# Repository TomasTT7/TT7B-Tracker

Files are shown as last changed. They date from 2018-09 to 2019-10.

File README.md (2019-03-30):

# TT7B-Tracker
This is the main repository for TT7B superpressure balloon tracker. It includes the board and schematic design files for Eagle, the current firmware and a couple of python scripts for decoding telemetry.

The tracker is in detail described in these two blog posts: [The TT7B Tracker](https://tt7hab.blogspot.com/2018/09/the-tt7b-tracker.html) and [The TT7B Tracker Vol. 2](https://tt7hab.blogspot.com/2019/03/the-tt7b-tracker-vol-2.html).

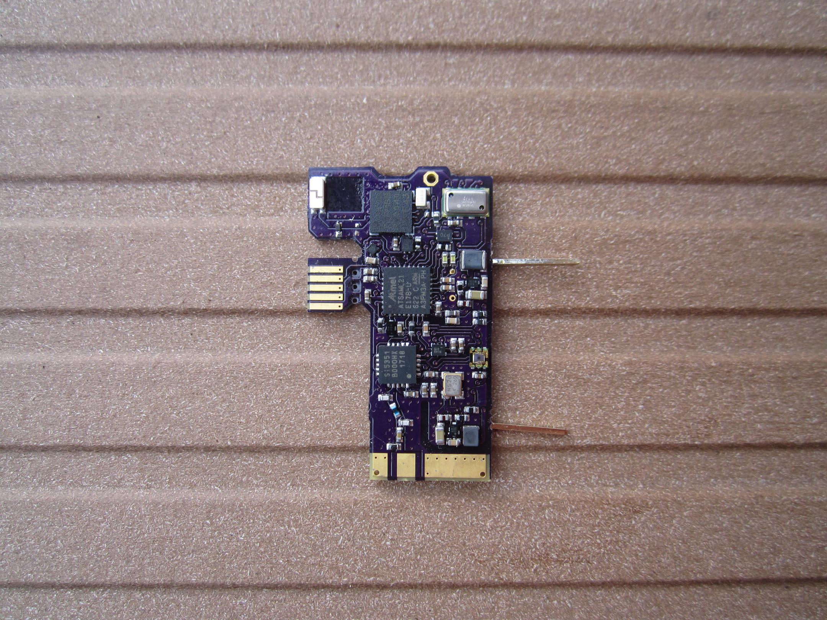
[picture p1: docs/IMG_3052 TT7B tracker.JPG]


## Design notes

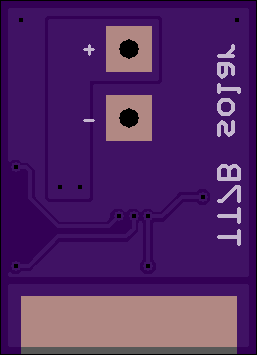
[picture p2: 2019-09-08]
Hardware/SPV1040 v1.0 bottom.png

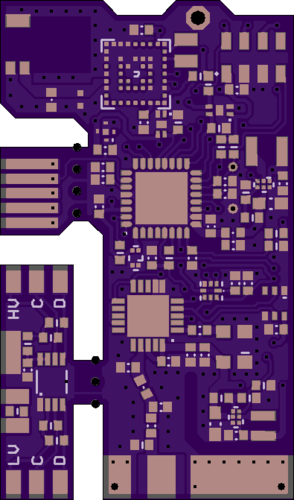
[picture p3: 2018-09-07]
Hardware/TT7B v1.0 top.png

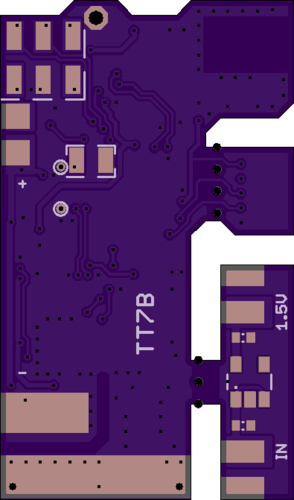
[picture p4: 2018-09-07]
Hardware/TT7B v1.0 bottom.png

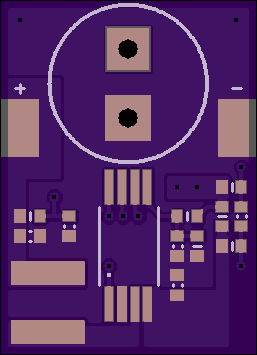
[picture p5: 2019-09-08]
Hardware/SPV1040 v1.0 top.png

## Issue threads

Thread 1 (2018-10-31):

LoRa_Gateway.py

SwiftFlying, 2018-10-31:
Hi,
I can't run the PY file. Can I send a EXE file to me?
Traceback (most recent call last):
File "C:\Users\hp1\Desktop\OV5640\LoRa_Gateway.py", line 30, in
from Tkinter import *
ModuleNotFoundError: No module named 'Tkinter'

TomasTT7, 2018-10-31:
You have to install all the modules LoRa_Gateway.py imports at the top of
the code to your Python. That is what the error is telling you. I don't
have an EXE file, I run it from python.

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

SwiftFlying, 2018-11-01:
LoRa_Gateway.py is finally able to run. Thank you for your help!

SwiftFlying, 2018-11-03:
Hi,
Is there any way to completely solve the problem of image errors?
I read your article. You found that the error was not from LORA transmission.It's from camera part。
Is there any interest in solving this problem completely?I can help you redesign the PCB part.I can make a new prototype for you.Of course, we can also switch to other camera tests.

SwiftFlying, 2018-11-19:
Hi,
I encountered a problem, unable to display the received pictures.
2018-11-18 20:31:50.76 SSDV from: TT7L ImageID: 2 PacketID: 0 1024x768 Quality: 4 No-FEC   snr: 42 rssi: -21 err: -0.4
2018-11-18 20:31:51.03 SSDV from: TT7L ImageID: 2 PacketID: 1 1024x768 Quality: 4 No-FEC   snr: 42 rssi: -21 err: -0.4
2018-11-18 20:31:51.33 SSDV from: TT7L ImageID: 2 PacketID: 2 1024x768 Quality: 4 No-FEC   snr: 41 rssi: -22 err: -0.4
2018-11-18 20:31:51.58 SSDV from: TT7L ImageID: 2 PacketID: 3 1024x768 Quality: 4 No-FEC   snr: 42 rssi: -22 err: -0.4
2018-11-18 20:31:51.86 SSDV from: TT7L ImageID: 2 PacketID: 4 1024x768 Quality: 4 No-FEC   snr: 42 rssi: -21 err: -0.4
2018-11-18 20:31:52.14 SSDV from: TT7L ImageID: 2 PacketID: 5 1024x768 Quality: 4 No-FEC   snr: 43 rssi: -21 err: -0.4
2018-11-18 20:31:52.39 SSDV from: TT7L ImageID: 2 PacketID: 6 1024x768 Quality: 4 No-FEC   snr: 44 rssi: -21 err: -0.4
2018-11-18 20:31:52.67 SSDV from: TT7L ImageID: 2 PacketID: 7 1024x768 Quality: 4 No-FEC   snr: 44 rssi: -21 err: -0.4
2018-11-18 20:31:52.95 SSDV from: TT7L ImageID: 2 PacketID: 8 1024x768 Quality: 4 No-FEC   snr: 42 rssi: -21 err: -0.4
2018-11-18 20:31:53.23 SSDV from: TT7L ImageID: 2 PacketID: 9 1024x768 Quality: 4 No-FEC   snr: 42 rssi: -22 err: -0.4
2018-11-18 20:31:53.51 SSDV from: TT7L ImageID: 2 PacketID: 10 1024x768 Quality: 4 No-FEC   snr: 43 rssi: -22 err: -0.4
2018-11-18 20:31:53.76 SSDV from: TT7L ImageID: 2 PacketID: 11 1024x768 Quality: 4 No-FEC   snr: 43 rssi: -21 err: -0.4
2018-11-18 20:31:54.04 SSDV from: TT7L ImageID: 2 PacketID: 12 1024x768 Quality: 4 No-FEC   snr: 42 rssi: -23 err: -0.4
2018-11-18 20:31:54.29 SSDV from: TT7L ImageID: 2 PacketID: 13 1024x768 Quality: 4 No-FEC   snr: 41 rssi: -22 err: -0.4
2018-11-18 20:31:54.58 SSDV from: TT7L ImageID: 2 PacketID: 14 1024x768 Quality: 4 No-FEC   snr: 41 rssi: -22 err: -0.4
2018-11-18 20:31:54.87 SSDV from: TT7L ImageID: 2 PacketID: 15 1024x768 Quality: 4 No-FEC   snr: 40 rssi: -25 err: -0.4
2018-11-18 20:31:55.22 SSDV from: TT7L ImageID: 2 PacketID: 16 1024x768 Quality: 4 No-FEC   snr: 42 rssi: -23 err: -0.4
2018-11-18 20:31:55.42 SSDV from: TT7L ImageID: 2 PacketID: 17 1024x768 Quality: 4 No-FEC   snr: 41 rssi: -22 err: -0.4
2018-11-18 20:31:55.68 SSDV from: TT7L ImageID: 2 PacketID: 18 1024x768 Quality: 4 No-FEC   snr: 40 rssi: -22 err: -0.4
2018-11-18 20:31:55.95 SSDV from: TT7L ImageID: 2 PacketID: 19 1024x768 Quality: 4 No-FEC   snr: 41 rssi: -23 err: -0.4
2018-11-18 20:31:56.22 SSDV from: TT7L ImageID: 2 PacketID: 20 1024x768 Quality: 4 No-FEC   snr: 41 rssi: -24 err: -0.4
2018-11-18 20:31:56.51 SSDV from: TT7L ImageID: 2 PacketID: 21 1024x768 Quality: 4 No-FEC   snr: 41 rssi: -23 err: -0.4
2018-11-18 20:31:56.78 SSDV from: TT7L ImageID: 2 PacketID: 22 1024x768 Quality: 4 No-FEC   snr: 43 rssi: -22 err: -0.4
2018-11-18 20:31:57.04 SSDV from: TT7L ImageID: 2 PacketID: 23 1024x768 Quality: 4 No-FEC   snr: 42 rssi: -21 err: -0.4
2018-11-18 20:31:57.31 SSDV from: TT7L ImageID: 2 PacketID: 24 1024x768 Quality: 4 No-FEC   snr: 41 rssi: -22 err: -0.4
2018-11-18 20:31:57.58 SSDV from: TT7L ImageID: 2 PacketID: 25 1024x768 Quality: 4 No-FEC   snr: 42 rssi: -23 err: -0.4
2018-11-18 20:31:57.87 SSDV from: TT7L ImageID: 2 PacketID: 26 1024x768 Quality: 4 No-FEC   snr: 41 rssi: -22 err: -0.4
2018-11-18 20:31:58.14 SSDV from: TT7L ImageID: 2 PacketID: 27 1024x768 Quality: 4 No-FEC   snr: 42 rssi: -23 err: -0.4
2018-11-18 20:31:58.42 SSDV from: TT7L ImageID: 2 PacketID: 28 1024x768 Quality: 4 No-FEC   snr: 43 rssi: -22 err: -0.4
2018-11-18 20:31:58.68 SSDV from: TT7L ImageID: 2 PacketID: 29 1024x768 Quality: 4 No-FEC   snr: 42 rssi: -23 err: -0.4
2018-11-18 20:31:58.97 SSDV from: TT7L ImageID: 2 PacketID: 30 1024x768 Quality: 4 No-FEC   snr: 40 rssi: -23 err: -0.4
2018-11-18 20:31:59.25 SSDV from: TT7L ImageID: 2 PacketID: 31 1024x768 Quality: 4 No-FEC   snr: 42 rssi: -23 err: -0.4
2018-11-18 20:31:59.53 SSDV from: TT7L ImageID: 2 PacketID: 32 1024x768 Quality: 4 No-FEC   snr: 41 rssi: -23 err: -0.4
2018-11-18 20:31:59.81 SSDV from: TT7L ImageID: 2 PacketID: 33 1024x768 Quality: 4 No-FEC   snr: 41 rssi: -23 err: -0.4
2018-11-18 20:32:00.06 SSDV from: TT7L ImageID: 2 PacketID: 34 1024x768 Quality: 4 No-FEC   snr: 40 rssi: -23 err: -0.4
2018-11-18 20:32:00.36 SSDV from: TT7L ImageID: 2 PacketID: 35 1024x768 Quality: 4 No-FEC   snr: 41 rssi: -23 err: -0.4
2018-11-18 20:32:00.62 SSDV from: TT7L ImageID: 2 PacketID: 36 1024x768 Quality: 4 No-FEC   snr: 42 rssi: -23 err: -0.4
2018-11-18 20:32:00.90 SSDV from: TT7L ImageID: 2 PacketID: 37 1024x768 Quality: 4 No-FEC   snr: 41 rssi: -23 err: -0.4
2018-11-18 20:32:01.17 SSDV from: TT7L ImageID: 2 PacketID: 38 1024x768 Quality: 4 No-FEC   snr: 39 rssi: -24 err: -0.4
2018-11-18 20:32:01.45 SSDV from: TT7L ImageID: 2 PacketID: 39 1024x768 Quality: 4 No-FEC   snr: 39 rssi: -24 err: -0.4
2018-11-18 20:32:01.75 SSDV from: TT7L ImageID: 2 PacketID: 40 1024x768 Quality: 4 No-FEC   snr: 41 rssi: -23 err: -0.4
2018-11-18 20:32:02.00 SSDV from: TT7L ImageID: 2 PacketID: 41 1024x768 Quality: 4 No-FEC   snr: 41 rssi: -23 err: -0.4
2018-11-18 20:32:02.28 SSDV from: TT7L ImageID: 2 PacketID: 42 1024x768 Quality: 4 No-FEC   snr: 40 rssi: -24 err: -0.4
2018-11-18 20:32:02.56 SSDV from: TT7L ImageID: 2 PacketID: 43 1024x768 Quality: 4 No-FEC   snr: 42 rssi: -24 err: -0.4
2018-11-18 20:32:02.84 SSDV from: TT7L ImageID: 2 PacketID: 44 1024x768 Quality: 4 No-FEC   snr: 41 rssi: -24 err: -0.4
2018-11-18 20:32:03.14 SSDV from: TT7L ImageID: 2 PacketID: 45 1024x768 Quality: 4 No-FEC   snr: 42 rssi: -23 err: -0.4
2018-11-18 20:32:03.39 SSDV from: TT7L ImageID: 2 PacketID: 46 1024x768 Quality: 4 No-FEC   snr: 39 rssi: -24 err: -0.4
2018-11-18 20:32:03.67 SSDV from: TT7L ImageID: 2 PacketID: 47 1024x768 Quality: 4 No-FEC   snr: 41 rssi: -24 err: -0.4
2018-11-18 20:32:03.95 SSDV from: TT7L ImageID: 2 PacketID: 48 1024x768 Quality: 4 No-FEC   snr: 43 rssi: -24 err: -0.4
2018-11-18 20:32:22.06 SSDV from: TT7L ImageID: 2 PacketID: 49 1024x768 Quality: 4 No-FEC   snr: 40 rssi: -22 err: -0.4
2018-11-18 20:32:23.17 SSDV from: TT7L ImageID: 2 PacketID: 53 1024x768 Quality: 4 No-FEC   snr: 24 rssi: -22 err: -0.4

How should I solve this problem?
Tom

TomasTT7, 2018-11-19:
Hi,

the gateway requires the following piece of code compiled in the main
folder as "SSDV.exe":

https://github.com/fsphil/ssdv

That is the code that decodes the packets to jpeg images and is called by
subprocess.Popen(args, shell=True) from decode_ssdv().

Tomas

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

SwiftFlying, 2018-11-19:
Thank you ！
I need to download the source code from here. https://github.com/fsphil/ssdv
Compile a APP "SSDV.exe" Sorry, I'm not very good at software.   What platform should I use to compile it?

Tom

TomasTT7, 2018-11-19:
I am sure there are more ways of compiling the code. I used Codeblocks.

If you don't want to bother with it, try downloading the exe file from my
google drive:

https://drive.google.com/open?id=1MGWpKZtEY6ANgXkNepjeXgWCe6bpOrCC

Tomas

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

SwiftFlying, 2018-11-22:
Thank you! Finally succeeded.

Closed 2019-11-03.

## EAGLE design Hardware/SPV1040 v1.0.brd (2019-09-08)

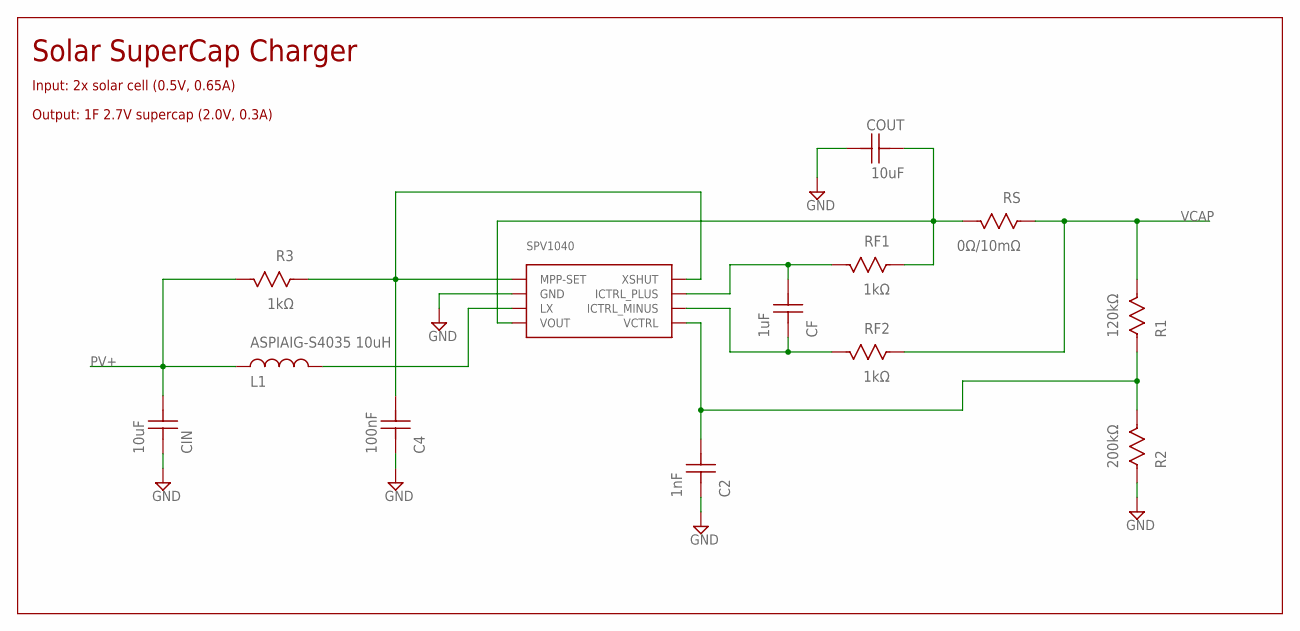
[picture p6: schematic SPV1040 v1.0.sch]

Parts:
C2: 1nF; CAP0402
C4: 100nF; CAP0402
CF: 1uF; CAP0402
CIN: 10uF; CAP0402
COUT: 10uF; CAP0402
L1: ASPIAIG-S4035 10uH; ASPIAIG-S4035
R1: 120kΩ; RES0402
R2: 200kΩ; RES0402
R3: 1kΩ; RES0402
RF1, RF2: 1kΩ; RES0402
RS: 0Ω/10mΩ; RES0402
U1: SPV1040

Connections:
GND: C2.P$1, C4.P$1, CIN.P$1, COUT.P$2, R2.P$1, U1.GND
N11: C4.P$2, R3.P$1, U1.MPP-SET, U1.XSHUT
unnamed: CF.P$2, RF1.P$2, U1.ICTRL_PLUS
unnamed: CF.P$1, RF2.P$2, U1.ICTRL_MINUS
unnamed: COUT.P$1, RF1.P$1, RS.P$2, U1.VOUT
unnamed: C2.P$2, R1.P$1, R2.P$2, U1.VCTRL
unnamed: L1.P$2, U1.LX
PV+: CIN.P$2, L1.P$1, R3.P$2
VCAP: R1.P$2, RF2.P$1, RS.P$1

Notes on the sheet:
Solar SuperCap Charger
Input: 2x solar cell (0.5V, 0.65A)
Output: 1F 2.7V supercap (2.0V, 0.3A)

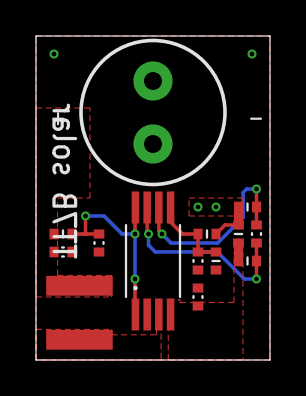
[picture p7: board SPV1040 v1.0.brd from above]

Board: 2 copper layers, 13.0 x 18.0 mm, 13 parts (0 on the bottom side), 9 nets.

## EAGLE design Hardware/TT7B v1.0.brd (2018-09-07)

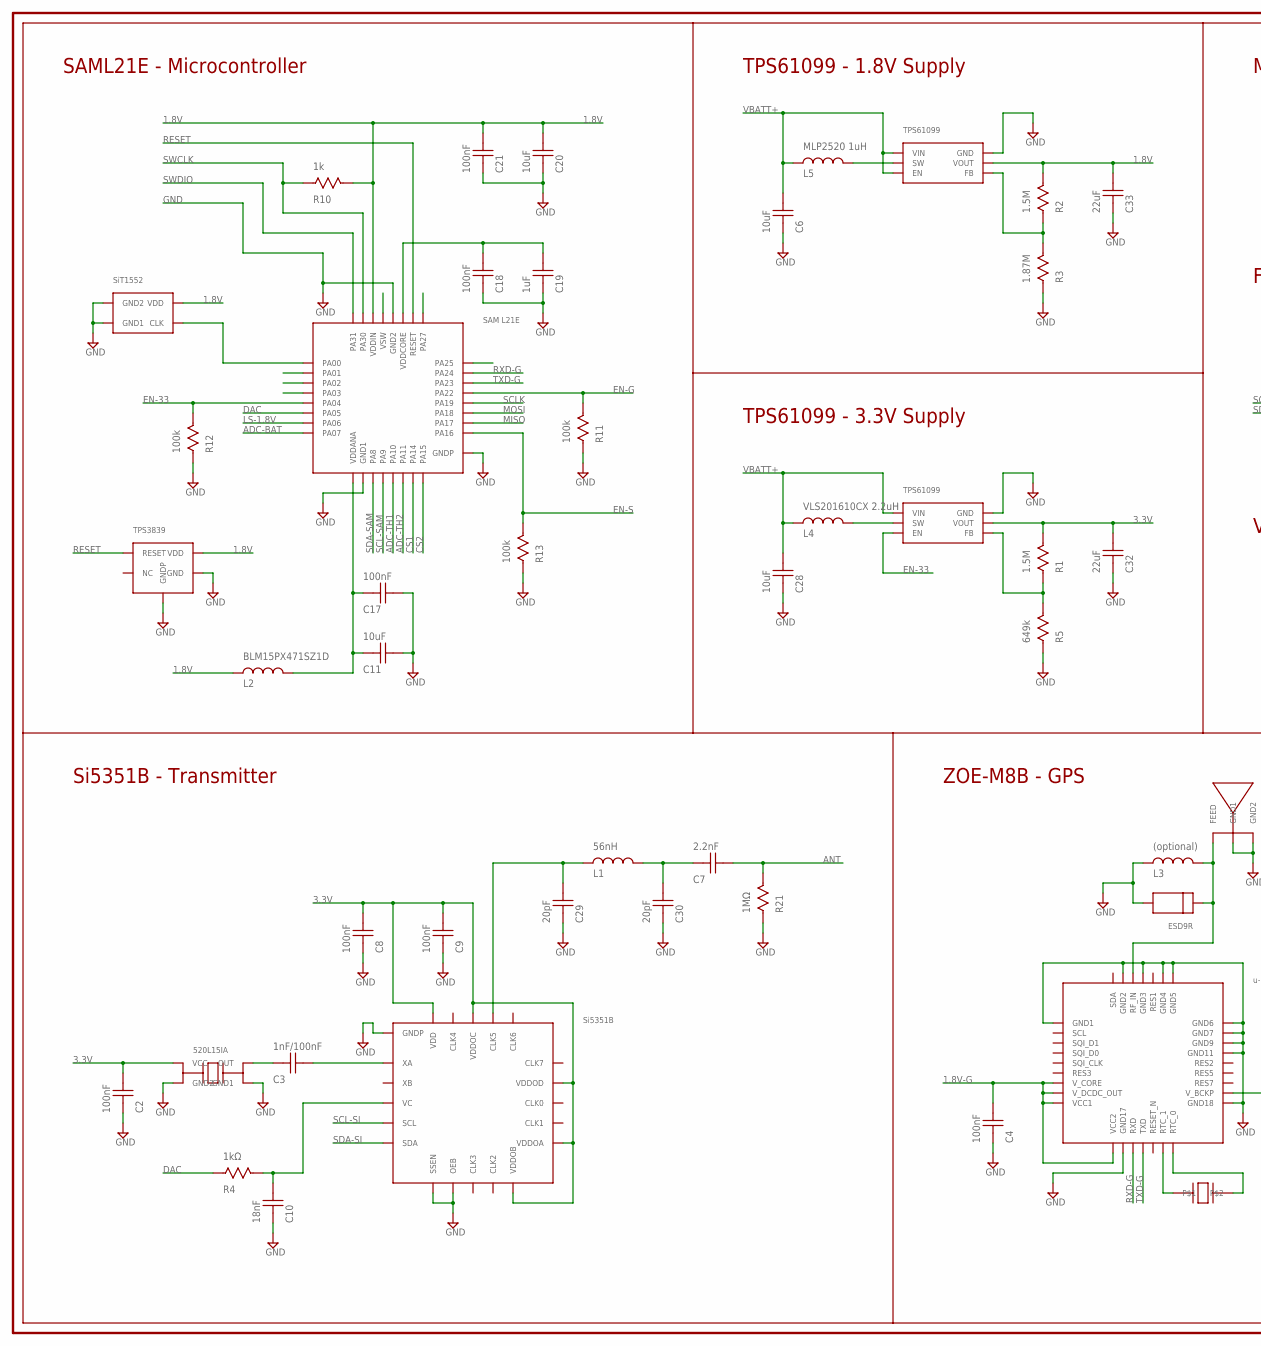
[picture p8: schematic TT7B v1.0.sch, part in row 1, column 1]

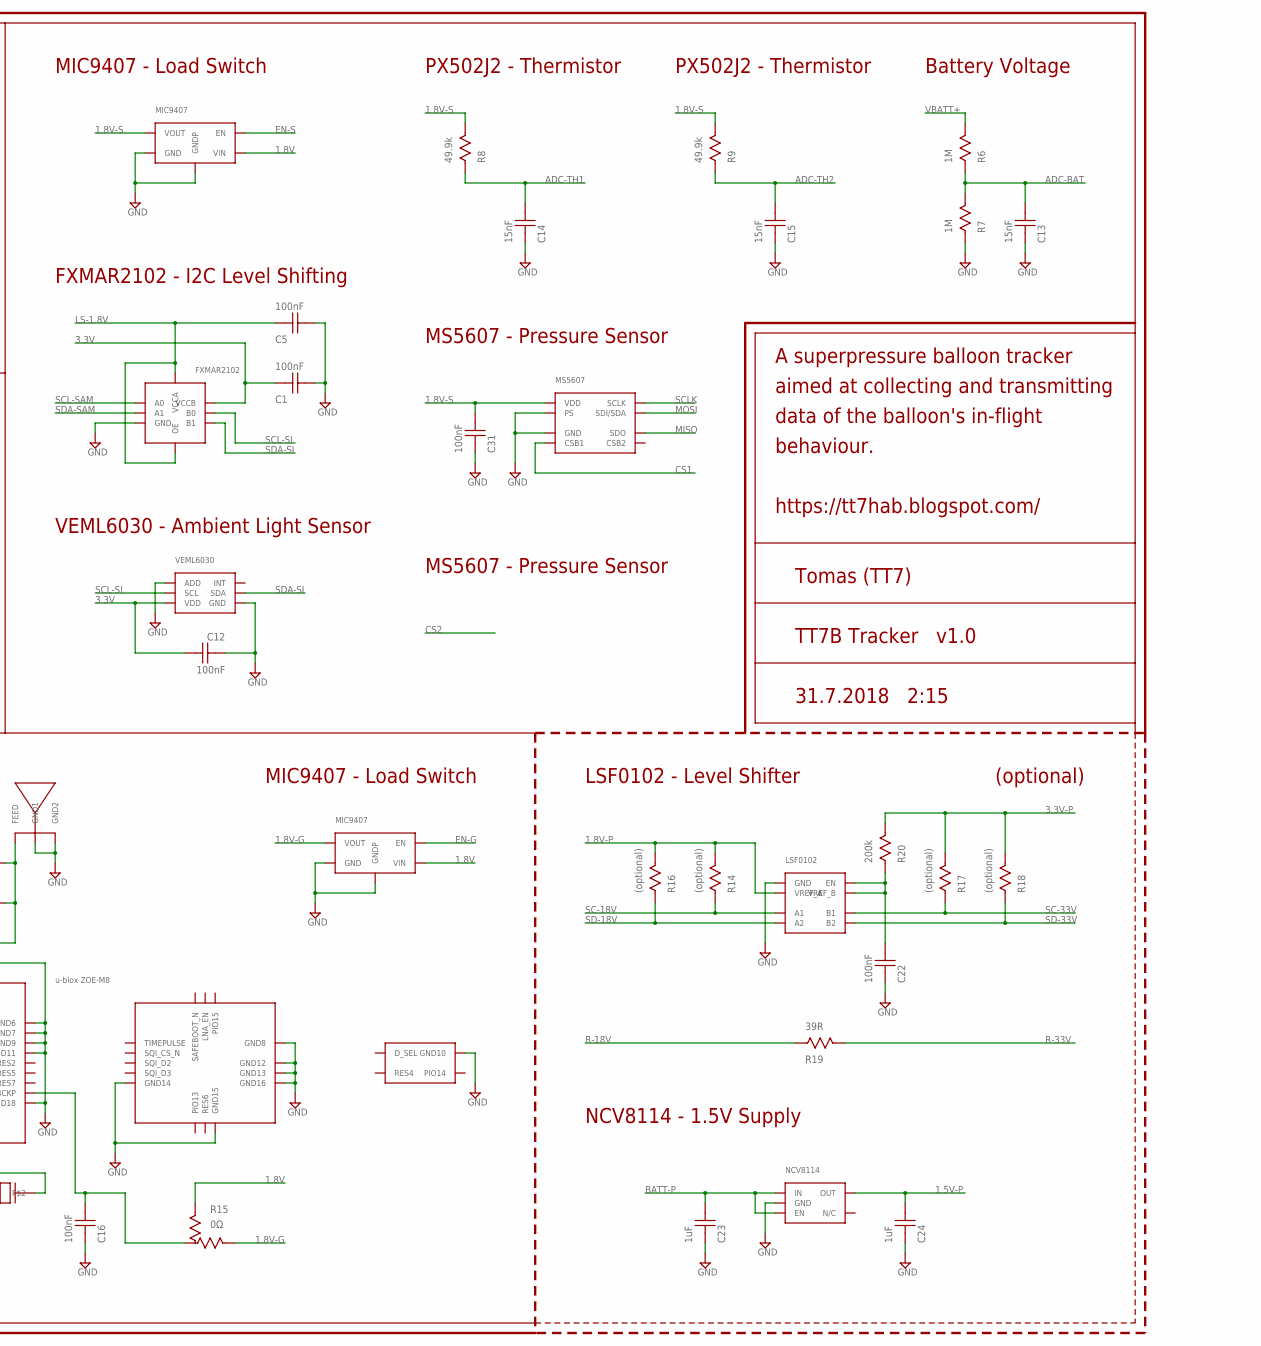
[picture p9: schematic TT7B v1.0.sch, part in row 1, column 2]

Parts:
C1, C2, C4, C5, C8, C9, C12, C16, C17, C18, C21, C22, C31: 100nF; CAP0402
C3: 1nF/100nF; CAP0402
C6, C11, C20, C28: 10uF; CAP0402
C7: 2.2nF; CAP0402
C10: 18nF; CAP0402
C13, C14, C15: 15nF; CAP0402
C19, C23, C24: 1uF; CAP0402
C29, C30: 20pF; CAP0402
C32, C33: 22uF; CAP0603
D1: ESD9R
L1: 56nH; IND0402
L2: BLM15PX471SZ1D; IND0402
L3: (optional); IND0402
L4: VLS201610CX 2.2uH; VLS201610CX
L5: MLP2520 1uH; MLP2520
R1, R2: 1.5M; RES0402
R3: 1.87M; RES0402
R4: 1kΩ; RES0402
R5: 649k; RES0402
R6, R7: 1M; RES0402
R8, R9: 49.9k; RES0402
R10: 1k; RES0402
R11, R12, R13: 100k; RES0402
R14, R16, R17, R18: (optional); RES0402
R15: 0Ω; RES0402-3
R19: 39R; RES0402
R20: 200k; RES0402
R21: 1MΩ; RES0402
U1: SAML21E18B-MUT
U2: UBLOX_ZOE-M8
U3: FXMAR2102
U4: 520L15IA
U5: CM8V-T1A
U6, U13: MIC9407
U7: MS5607
U8: LSF0102
U9: NCV8114
U10: W3011A
U11: SI5351B
U12: TPS3839; TPS383
U14: SIT1552
U15: VEML6030
U16, U17: TPS61099

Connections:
1.5V-P: C24.P$2, U9.OUT
1.8V: C20.P$2, C21.P$2, C33.P$2, L2.P$1, R2.P$2, R10.P$2, R15.1, U1.VDDIN, U6.VIN, U12.VDD, U13.VIN, U14.VDD, U16.VOUT
1.8V-G: C4.P$2, R15.3, U2.VCC1, U2.VCC2, U2.V_CORE, U2.V_DCDC_OUT, U6.VOUT
1.8V-P: R14.P$2, R16.P$2, U8.VREF_A
1.8V-S: C31.P$2, R8.P$2, R9.P$2, U7.VDD, U13.VOUT
3.3V: C1.P$1, C2.P$2, C8.P$2, C9.P$2, C12.P$2, C32.P$2, R1.P$2, U3.VCCB, U4.VCC, U11.VDD, U11.VDDOA, U11.VDDOB, U11.VDDOC, U11.VDDOD, U15.VDD, U17.VOUT
3.3V-P: R17.P$2, R18.P$2, R20.P$2
ADC-BAT: C13.P$2, R6.P$1, R7.P$2, U1.PA07
ADC-TH1: C14.P$2, R8.P$1, U1.PA10
ADC-TH2: C15.P$2, R9.P$1, U1.PA11
ANT: C7.P$2, R21.P$2
BATT-P: C23.P$2, U9.EN, U9.IN
CS1: U1.PA14, U7.CSB1
CS2: U1.PA15
DAC: R4.P$1, U1.PA05
EN-33: R12.P$2, U1.PA04, U17.EN
EN-G: R11.P$2, U1.PA22, U6.EN
EN-S: R13.P$2, U1.PA16, U13.EN
GND: C1.P$2, C2.P$1, C4.P$1, C5.P$2, C6.P$1, C8.P$1, C9.P$1, C10.P$1, C11.P$2, C12.P$1, C13.P$1, C14.P$1, C15.P$1, C16.P$1, C17.P$2, C18.P$1, C19.P$1, C20.P$1, C21.P$1, C22.P$1, C23.P$1, C24.P$1, C28.P$1, C29.P$1, C30.P$1, C31.P$1, C32.P$1, C33.P$1, D1.2, L3.P$1, R3.P$1, R5.P$1, R7.P$1, R11.P$1, R12.P$1, R13.P$1, R21.P$1, U1.GND1, U1.GND2, U1.GNDP, U2.GND1, U2.GND2, U2.GND3, U2.GND4, U2.GND5, U2.GND6, U2.GND7, U2.GND8, U2.GND9, U2.GND10, U2.GND11, U2.GND12, U2.GND13, U2.GND14, U2.GND15, U2.GND16, U2.GND17, U2.GND18, U3.GND, U4.GND1, U4.GND2, U6.GND, U6.GNDP, U7.GND, U7.PS, U8.GND, U9.GND, U10.GND1, U10.GND2, U11.GNDP, U11.OEB, U11.SSEN, U12.GND, U12.GNDP, U13.GND, U13.GNDP, U14.GND1, U14.GND2, U15.ADD, U15.GND, U16.GND, U17.GND
LS-1.8V: C5.P$1, U1.PA06, U3.OE, U3.VCCA
MISO: U1.PA17, U7.SDO
MOSI: U1.PA18, U7.SDI/SDA
unnamed: D1.1, L3.P$2, U2.RF_IN, U10.FEED
unnamed: C3.P$2, U11.XA
unnamed: U2.RTC_1, U5.P$1
unnamed: U2.RTC_0, U5.P$2
unnamed: C16.P$2, R15.2, U2.V_BCKP
unnamed: C18.P$2, C19.P$2, U1.VDDCORE
unnamed: C22.P$2, R20.P$1, U8.EN, U8.VREF_B
unnamed: C11.P$1, C17.P$1, L2.P$2, U1.VDDANA
unnamed: C7.P$1, C30.P$2, L1.P$2
unnamed: R2.P$1, R3.P$2, U16.FB
unnamed: R1.P$1, R5.P$2, U17.FB
unnamed: L4.P$2, U17.SW
unnamed: L5.P$2, U16.SW
unnamed: C29.P$2, L1.P$1, U11.CLK5
unnamed: C3.P$1, U4.OUT
unnamed: C10.P$2, R4.P$2, U11.VC
R-18V: R19.P$1
R-33V: R19.P$2
RESET: U1.RESET, U12.RESET
RXD-G: U1.PA24, U2.RXD
SC-18V: R14.P$1, U8.A1
SC-33V: R17.P$1, U8.B1
SCL-SAM: U1.PA09 (PA9), U3.A0
SCL-SI: U3.B0, U11.SCL, U15.SCL
SCLK: U1.PA19, U7.SCLK
SD-18V: R16.P$1, U8.A2
SD-33V: R18.P$1, U8.B2
SDA-SAM: U1.PA08 (PA8), U3.A1
SDA-SI: U3.B1, U11.SDA, U15.SDA
SWCLK: R10.P$1, U1.PA30
SWDIO: U1.PA31
TXD-G: U1.PA23, U2.TXD
VBATT+: C6.P$2, C28.P$2, L4.P$1, L5.P$1, R6.P$2, U16.EN, U16.VIN, U17.VIN
XIN32: U1.PA00, U14.CLK

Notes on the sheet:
Battery Voltage
PX502J2 - Thermistor
MS5607 - Pressure Sensor
MIC9407 - Load Switch
VEML6030 - Ambient Light Sensor
FXMAR2102 - I2C Level Shifting
Si5351B - Transmitter
SAML21E - Microcontroller
ZOE-M8B - GPS
TPS61099 - 3.3V Supply
TPS61099 - 1.8V Supply
LSF0102 - Level Shifter
NCV8114 - 1.5V Supply
TT7B Tracker v1.0
Tomas (TT7)
31.7.2018 2:15
A superpressure balloon tracker
aimed at collecting and transmitting
data of the balloon's in-flight
behaviour.
https://tt7hab.blogspot.com/
(optional)

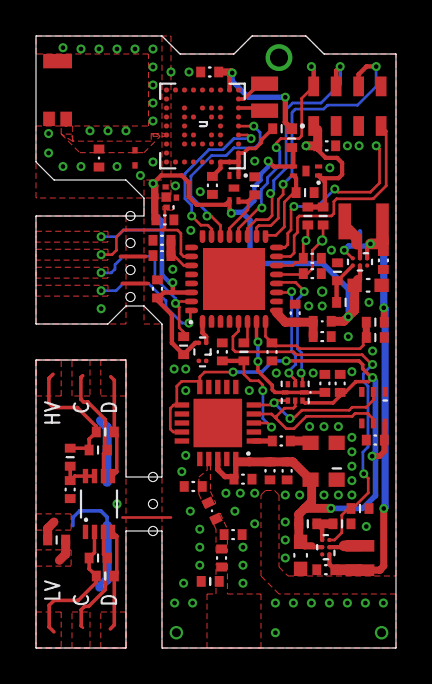
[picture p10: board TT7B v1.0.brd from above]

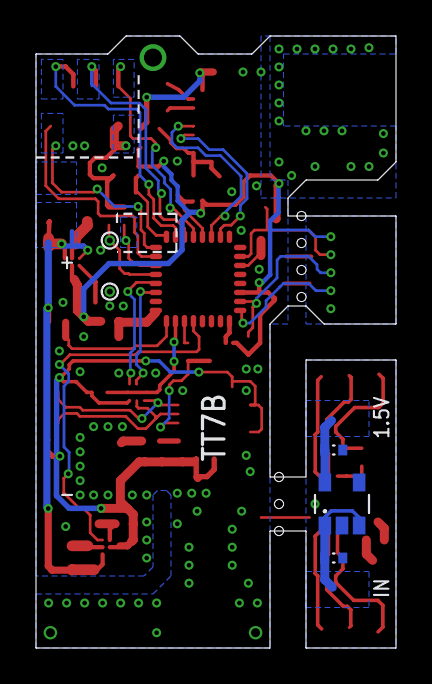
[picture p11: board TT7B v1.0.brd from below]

Board: 2 copper layers, 20.0 x 34.0 mm, 74 parts (3 on the bottom side), 52 nets.

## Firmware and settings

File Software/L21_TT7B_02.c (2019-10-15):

/*
	TT7B Superpressure Balloon Tracker firmware.
	
		More info on the hardware:
			http://tt7hab.blogspot.com/2018/09/the-tt7b-tracker.html
		
		by TT7 on 2018/09/16.
*/


#include "sam.h"
#include "L21_ADC.h"
#include "L21_APRS.h"
#include "L21_DAC.h"
#include "L21_GCLK.h"
#include "L21_GEOFENCE.h"
#include "L21_MS5607.h"
#include "L21_NVM.h"
#include "L21_OSC.h"
#include "L21_PM.h"
#include "L21_PORT.h"
#include "L21_RSTC.h"
#include "L21_RTC.h"
#include "L21_SERCOM_I2C.h"
#include "L21_SERCOM_SPI.h"
#include "L21_SERCOM_USART.h"
#include "L21_SI5351B.h"
#include "L21_SUPC.h"
#include "L21_SysTick.h"
#include "L21_TC.h"
#include "L21_VEML6030.h"
#include "L21_WatchDog.h"
#include "L21_ZOE_M8B.h"


uint32_t SysTick_CLK = 4000000;										// default MCLK after MCU reset


// Reset_Handler ---------------------------------------------------------------------------------
/*
	This is the code that gets called on processor reset.
	To initialize the device, and call the main() routine.
	
	Definition: startup_saml21.c
*/


// Main Function ---------------------------------------------------------------------------------
int main(void)
{
    /* Initialization */
	SystemInit();													// 4MHz MCLK - OSC16M
	WatchDog_enable(0x0B);											// 16s period
	uint8_t last_reset = RSTC_get_reset_source();
    SysTick_delay_init();
	
	/* Initialize BOD33 */
	SUPC_BOD33_disable();
	SUPC_BOD33_set_level(1);										// decrease trigger voltage to ~1.55V
	SUPC_BOD33_enable();
	
	/* Initialize RTC */
	uint32_t RTC_current = 0;
	
	OSC_enable_XOSC32K();											// enable 32.768kHz TCXO input signal
	RTC_mode0_enable(0x0B, 2764800);								// 31.25ms resolution, 24 hours initial compare match
	RTC_mode0_set_count(0);											// reset RTC to count from 0 in case this isn't POR
	
	/* XOSC32K */
	GCLK_x_enable(0, 5, 1, 0, 0);									// 32.768kHz MCLK - XOSC32K
	SysTick_CLK = 32768;
	
	/* Minimum Battery Voltage */
	uint16_t batt_V_raw = 0;
	
	while(batt_V_raw < 841)											// 0.75V minimum Vbatt to continue
	{
		ADC_enable(0, 5, 1, 6, 4, 0);								// 16.384kHz ADC clock, VDDANA reference, 64x averaging
		batt_V_raw = ADC_sample_channel_x(0x07);					// battery voltage raw
		ADC_disable();
		
		SysTick_delay_s(1);
		
		/* WatchDog Reset */
		WatchDog_reset();											// WatchDog Reset or let it reset every 16s
	}
	
	/* OSC16M */
	GCLK_x_enable(0, 6, 0, 0, 0);									// 4MHz MCLK - OSC16M
	SysTick_CLK = 4000000;
	
	/* Initialize Backlogging */
	uint16_t backlog_index = 0;
	
	/* Initialize Counter */
	uint32_t count = 0;
	
	/* WatchDog Reset */
	WatchDog_reset();
	
	/* Initialize Sensors */
	PORT_switch_enable(2);											// POWER to SENSORS on
	
	/* MS5607 Calibrations and Measurements */
	SERCOM_SPI_enable();											// 2MHz F_SPI (MCK / 2)
	
	MS5607_cmd_Reset(1, 0);											// after power-on, to make sure that calibration PROM gets loaded
	MS5607_cmd_Reset(2, 0);											// after power-on, to make sure that calibration PROM gets loaded
	SysTick_delay_ms(5);
	
	MS5607_cmd_PROMread(1);											// reads and stores 16 calibration bytes for MS5607_1
	MS5607_cmd_PROMread(2);											// reads and stores 16 calibration bytes for MS5607_2
	
	MS5607_cmd_Convert(1, 0x48);									// Oversampling Ratio = 4096, resolution = 0.024mbar, conversion time = 9.04ms
	SysTick_delay_ms(10);
	uint32_t MS1_pres_raw = MS5607_cmd_ADCread(1);
	
	MS5607_cmd_Convert(1, 0x58);									// Oversampling Ratio = 4096, resolution = 0.002°C, conversion time = 9.04ms
	SysTick_delay_ms(10);
	uint32_t MS1_temp_raw = MS5607_cmd_ADCread(1);
	
	MS5607_cmd_Convert(2, 0x48);									// Oversampling Ratio = 4096, resolution = 0.024mbar, conversion time = 9.04ms
	SysTick_delay_ms(10);
	uint32_t MS2_pres_raw = MS5607_cmd_ADCread(2);
	
	MS5607_cmd_Convert(2, 0x58);									// Oversampling Ratio = 4096, resolution = 0.002°C, conversion time = 9.04ms
	SysTick_delay_ms(10);
	uint32_t MS2_temp_raw = MS5607_cmd_ADCread(2);
	
	SERCOM_SPI_disable();
	
	/* ADC Measurements */
	ADC_enable(0, 5, 1, 6, 4, 0);									// 2MHz ADC clock, VDDANA reference, 64x averaging
	batt_V_raw = ADC_sample_channel_x(0x07);						// battery voltage raw
	uint16_t therm1_raw = ADC_sample_channel_x(0x12);				// thermistor 1 voltage
	uint16_t therm2_raw = ADC_sample_channel_x(0x13);				// thermistor 2 voltage
	ADC_disable();
	
	/* Sensors - Power-Down */
	PORT_switch_disable(2);											// POWER to SENSORS off
	
	/* Initialize VEML6030 */
	PORT_switch_enable(3);											// POWER to 3.3V on
	PORT_switch_enable(4);											// POWER to TRANSLATOR on
	SERCOM_I2C_enable(4000000, 90000);								// 4MHz MCK, 90kHz I2C
	
	VEML6030_disable();
	SysTick_delay_ms(50);											// give 3.3V circuit short on time
	
	SERCOM_I2C_disable();
	PORT_switch_disable(4);											// POWER to TRANSLATOR off
	PORT_switch_disable(3);											// POWER to 3.3V off
	
	/* Short Delay */
	SysTick_delay_ms(100);
	
	/* WatchDog Reset */
	WatchDog_reset();
	
	/* Initialize GPS */
	uint16_t year		= 0;
	uint8_t month		= 0;
	uint8_t day			= 0;
	uint8_t hour		= 0;
	uint8_t min			= 0;
	uint8_t sec			= 0;
	uint8_t valid		= 0;
	uint8_t fixType		= 0;
	uint8_t gnssFixOK	= 0;
	uint8_t psmState	= 0;
	uint8_t numSV		= 0;
	float lon			= 0.0;
	float lat			= 0.0;
	int32_t hMSL		= 0;
	uint32_t hAcc		= 0;
	uint32_t vAcc		= 0;
	uint16_t pDOP		= 0;
	uint8_t noGPS		= 0;
	uint8_t valid_time	= 0;
	
	uint8_t GPS_buffer[110];
	
	uint8_t ack			= 0;
	uint8_t checksum	= 0;
	uint8_t reinit		= 0;
	
	PORT_switch_enable(1);											// POWER to GPS on
	SERCOM_USART_enable(4000000, 9600);								// initial baud rate 9600
	
	ZOE_M8B_send_message((uint8_t*) 0xFF, 1);						// wakes up receiver if it is in Inactive state, otherwise ignored
	SysTick_delay_ms(500);											// if interval too short, receiver may not be ready to process configuration messages
	
	ZOE_M8B_set_port(3);											// 115200 baud, only UBX protocol
	SysTick_delay_ms(1500);											// must be >1s, because in case of baud mismatch u-blox disables UART for 1s
	
	SERCOM_USART_disable();
	SERCOM_USART_enable(4000000, 115200);							// baud rate 115200
	
	clear_buffer(GPS_buffer, 110);
	ack = ZOE_M8B_get_port(GPS_buffer, 230000);						// request confirmation of higher baud rate
	
	uint32_t baud_val = (GPS_buffer[16] << 16) | (GPS_buffer[15] << 8) | GPS_buffer[14];
	
	if(ack != 1 || baud_val != 115200)								// if it fails continue with default baud rate
	{
		baud_val = 9600;
		SERCOM_USART_disable();
		SERCOM_USART_enable(4000000, baud_val);						// baud rate 9600
	}
	
	/* WatchDog Reset */
	WatchDog_reset();
	
	ack = ZOE_M8B_power_saving(0);									// Continuous mode
	ack = ZOE_M8B_set_GNSS_system(1);								// GPS and QZSS only
	ack = ZOE_M8B_set_update_rate(3);								// 100ms between measurements, 1 measurement per solution
	ack = ZOE_M8B_set_dynamic_model(6);								// Airborne <1g (50,000m ceiling)
	//ack = ZOE_M8B_AssistNow_Autonomous(1);							// enable AssistNow Autonomous
	ack = ZOE_M8B_save_current_configuration();
	
/*	while(1)
	{
*/		/* WatchDog Reset */
/*		WatchDog_reset();
		
		clear_buffer(GPS_buffer, 110);
		checksum = ZOE_M8B_get_solution(GPS_buffer, 230000);		// 1.5s timeout with 4MHz MCLK
		
		if(checksum == 1)
		{
			ZOE_M8B_parse_solution(GPS_buffer, &year, &month, &day, &hour, &min, &sec, &valid, &fixType, &gnssFixOK,
									&psmState, &numSV, &lon, &lat, &hMSL, &hAcc, &vAcc, &pDOP);
			
			if((valid & 0x04) == 0x04 || (valid & 0x03) == 0x03) valid_time = 1;
			else valid_time = 0;
			
			if(gnssFixOK && valid_time && numSV >= 7) break;		// valid fix, time and date and minimum number of satellites condition
		}
		
		RTC_current = RTC_get_current_count();		
		if(RTC_current > 9600) break;								// 5min timeout
	}
*/	
	/* WatchDog Reset */
	WatchDog_reset();
	
	/* AssistNow Autonomous */
/*	uint8_t ANAstatus = 0;
	
	while(1)														// wait for AssistNow Autonomous
	{
		checksum = ZOE_M8B_get_ANA_status(GPS_buffer, 230000);
		
		if(checksum)
		{
			ZOE_M8B_parse_ANA_status(GPS_buffer, &ANAstatus);
			if(!ANAstatus) break;
		}
	}
	
	ack = ZOE_M8B_save_current_configuration();
*/	
	SERCOM_USART_disable();
	PORT_switch_disable(1);											// POWER to GPS off
	
	/* Main Loop */
	while(1)
	{
		/* Counter Update */
		count++;
		
		/* WatchDog Reset */
		WatchDog_reset();
		
		/* GPS - Wake Up */
/*		PORT_switch_enable(1);										// POWER to GPS on
		SERCOM_USART_enable(4000000, baud_val);						// operating baud rate (9600 or 115200)
		
		ZOE_M8B_send_message((uint8_t*) 0xFF, 1);					// wakes up receiver if it is in Inactive state, otherwise ignored
		SERCOM_USART_disable();
*/		
		/* Sensors - Power-Up */
		PORT_switch_enable(2);										// POWER to SENSORS on
		
		/* MS5607 */
		SERCOM_SPI_enable();										// 2MHz F_SPI (MCK / 2)
		MS5607_cmd_Reset(1, 0);										// after power-on, to make sure that calibration PROM gets loaded
		MS5607_cmd_Reset(2, 0);										// after power-on, to make sure that calibration PROM gets loaded
		SysTick_delay_ms(5);

		MS5607_cmd_Convert(1, 0x48);								// Oversampling Ratio = 4096, resolution = 0.024mbar, conversion time = 9.04ms
		SysTick_delay_ms(10);
		MS1_pres_raw = MS5607_cmd_ADCread(1);
		
		MS5607_cmd_Convert(1, 0x58);								// Oversampling Ratio = 4096, resolution = 0.002°C, conversion time = 9.04ms
		SysTick_delay_ms(10);
		MS1_temp_raw = MS5607_cmd_ADCread(1);
		
		MS5607_cmd_Convert(2, 0x48);								// Oversampling Ratio = 4096, resolution = 0.024mbar, conversion time = 9.04ms
		SysTick_delay_ms(10);
		MS2_pres_raw = MS5607_cmd_ADCread(2);
		
		MS5607_cmd_Convert(2, 0x58);								// Oversampling Ratio = 4096, resolution = 0.002°C, conversion time = 9.04ms
		SysTick_delay_ms(10);
		MS2_temp_raw = MS5607_cmd_ADCread(2);
		
		SERCOM_SPI_disable();
		
		/* ADC Averaged */
		ADC_enable(0, 5, 1, 6, 4, 0);								// 2MHz ADC clock, VDDANA reference, 64x averaging
		batt_V_raw = ADC_sample_channel_x(0x07);					// battery voltage raw
		therm1_raw = ADC_sample_channel_x(0x12);					// thermistor 1 voltage
		therm2_raw = ADC_sample_channel_x(0x13);					// thermistor 2 voltage
		ADC_disable();
		
		/* Sensors - Power-Down */
		PORT_switch_disable(2);										// POWER to SENSORS off
		
		/* GPS - Wake Up */
		PORT_switch_enable(1);										// POWER to GPS on - after measurements by SENSORS
		SERCOM_USART_enable(4000000, baud_val);						// operating baud rate (9600 or 115200)
		
		ZOE_M8B_send_message((uint8_t*) 0xFF, 1);					// wakes up receiver if it is in Inactive state, otherwise ignored
		SERCOM_USART_disable();
		
		/* MS5607 - Results */
		float MS1_pres, MS1_temp, MS2_pres, MS2_temp;
		MS5607_calculate_results(1, MS1_pres_raw, MS1_temp_raw, &MS1_pres, &MS1_temp);
		MS5607_calculate_results(2, MS2_pres_raw, MS2_temp_raw, &MS2_pres, &MS2_temp);
		
		/* WatchDog Reset */
		WatchDog_reset();
		
		/* MCU Temperature Sensor */
		uint32_t average_n = 64;									// number of samples to average
		uint32_t raw_collected = 0;									// maximum 1,048,832 samples
		
		NVM_wait_states(3);											// NVM Read Wait States: 0-15, default 0, 3 for 48MHz PL2 operation
		PM_set_performance_level(2, 0);
		OSC_enable_DFLL48M_open();
		GCLK_x_enable(0, 7, 15, 0, 0);								// 3.2MHz MCLK - DFLL48M / 15
		SysTick_CLK = 3200000;
		
		SUPC_temperature_sensor(1);
		ADC_enable(0, 0, 0, 0, 0, 63);								// 1.6MHz ADC clock, INTREF reference, 12-bit resolution
		
		for(uint32_t i = 0; i < average_n; i++)
		{
			raw_collected += ADC_sample_channel_x(0x18);			// temperature sensor raw, one measurement 13 clock cycles
		}
		uint16_t temp_sensor_raw = raw_collected / average_n;		// average raw ADC value
		
		ADC_disable();
		SUPC_temperature_sensor(0);
		
		float MCU_temp = ADC_temperature_mcu(temp_sensor_raw);		// [°C]
		
		/* OSC16M */
		GCLK_x_enable(0, 6, 0, 0, 0);								// 4MHz MCLK - OSC16M
		SysTick_CLK = 4000000;
		OSC_disable_DFLL48M();
		PM_set_performance_level(0, 0);
		NVM_wait_states(0);											// NVM Read Wait States: 0-15, default 0, 3 for 48MHz PL2 operation
		
		/* WatchDog Reset */
		WatchDog_reset();
		
		/* VEML6030 */
		uint32_t light_raw = 0;
		float ambient_light = 0.0;
		
		PORT_switch_enable(3);										// POWER to 3.3V on
		PORT_switch_enable(4);										// POWER to TRANSLATOR on
		SERCOM_I2C_enable(4000000, 90000);							// 4MHz MCK, 90kHz I2C
		
		ack = VEML6030_enable(0b10, 0b1100);						// Gain 1/8, Integration Time 25ms, maximum 120klux, resolution 1.8432lux
		
		if(!ack)
		{
			SysTick_delay_ms(55);
			VEML6030_enable(0b10, 0b1100);							// try again
		}
		
		SysTick_delay_ms(55);										// for consistent readings (2x integration time + 5ms)
		light_raw = VEML6030_get_measurement_result();
		ambient_light = VEML6030_calculate_lux((uint16_t)light_raw, 0b10, 0b1100);
			
		if(light_raw < 20)											// if measurement < 37 lux
		{
			VEML6030_enable(0b01, 0b0000);							// Gain 2, Integration Time 100ms, maximum 1887lux, resolution 0.0288lux
			SysTick_delay_ms(205);									// for consistent readings (2x integration time + 5ms)
			
			light_raw = VEML6030_get_measurement_result();
			ambient_light = VEML6030_calculate_lux((uint16_t)light_raw, 0b01, 0b0000);
		}
		
		VEML6030_disable();
		SERCOM_I2C_disable();
		
		PORT_switch_disable(4);										// POWER to TRANSLATOR off
		PORT_switch_disable(3);										// POWER to 3.3V off
		
		/* WatchDog Reset */
		WatchDog_reset();
		
		/* GPS - Get Data */
		noGPS = 0;
		uint8_t tout = 15;
		uint16_t attempts = 0;
		
		SERCOM_USART_enable(4000000, baud_val);						// operating baud rate (9600 or 115200)
		
		while(1)													// delay until GPS module responds properly
		{
			clear_buffer(GPS_buffer, 110);
			checksum = ZOE_M8B_get_dynamic_model(GPS_buffer, 16000);
			
			tout--;
			
			if(!tout || checksum == 1) break;
		}
		
		if(tout)													// previous request didn't time out, communication works
		{
			/* Dynamic Model Check */
			uint8_t dynamic_model = 0;
			
			ZOE_M8B_parse_dynamic_model(GPS_buffer, &dynamic_model);
			
			if(dynamic_model != 6)
			{
				clear_buffer(GPS_buffer, 110);
				ack = ZOE_M8B_set_dynamic_model(6);					// Airborne <1g (50,000m ceiling)
			}
			
			/* Data Acquisition */
			while(1)
			{
				/* WatchDog Reset */
				WatchDog_reset();
				
				attempts++;
				
				clear_buffer(GPS_buffer, 110);
				checksum = ZOE_M8B_get_solution(GPS_buffer, 230000);		// 1.5s timeout with 4MHz MCLK
				
				if(checksum == 1)
				{
					ZOE_M8B_parse_solution(GPS_buffer, &year, &month, &day, &hour, &min, &sec, &valid, &fixType, &gnssFixOK,
											&psmState, &numSV, &lon, &lat, &hMSL, &hAcc, &vAcc, &pDOP);
					
					if((valid & 0x04) == 0x04 || (valid & 0x03) == 0x03) valid_time = 1;
					else valid_time = 0;
					
					if(gnssFixOK && valid_time && numSV >= 5) break;		// valid fix, time and date and minimum number of satellites condition
				}
				
				if(attempts > 390)									// limit acquisition to 39s (390 attempts at 10Hz) - ephemeris cycle 18-36s
				{
					noGPS = 1;										// transmit packet without position
					reinit++;
					break;
				}
			}
		}
		else
		{
			noGPS = 1;												// transmit packet without position
			reinit++;
		}
		
		if(!noGPS) reinit = 0;										// zero counter of failed fix acquisitions in row
		
		/* WatchDog Reset */
		WatchDog_reset();
		
		/* AssistNow Autonomous */
/*		uint32_t ANAtimeout = RTC_get_current_count();
	
		while(1)													// wait for AssistNow Autonomous
		{
			checksum = ZOE_M8B_get_ANA_status(GPS_buffer, 230000);
			
			if(checksum)
			{
				ZOE_M8B_parse_ANA_status(GPS_buffer, &ANAstatus);	
				if(!ANAstatus) break;
			}
			
			if((RTC_get_current_count() - ANAtimeout) > 2880) break;	// 90s timeout
			
*/			/* WatchDog Reset */
/*			WatchDog_reset();
		}
*/		
		ack = ZOE_M8B_save_current_configuration();
		
		SERCOM_USART_disable();
		PORT_switch_disable(1);										// POWER to GPS off
		
		/* Active Time */
		uint16_t active_time;
		
		RTC_current = RTC_get_current_count();
		active_time = (uint16_t)((float)RTC_current * 0.3125);		// [0.1s], 100ms resolution (rounded down)
		
		if(active_time > 999) active_time = 999;					// set upper limit - 99.9s
		
		/* Last Reset */
		if(count > 1) last_reset = 0;								// show reset source only after it happened
		
		/* Backlog */
		if((count % 10) == 0 && !noGPS)								// store backlog every X cycles, but only with valid GPS data
		{
			uint8_t bck_buffer[37];
			
			APRS_backlog_encode(bck_buffer, lat, lon, (uint16_t)hMSL, MCU_temp, therm1_raw, therm2_raw, MS1_temp, MS2_temp,
								(uint32_t)MS1_pres, (uint32_t)MS2_pres, year, month, day, hour, min, batt_V_raw, ambient_light,
								numSV, active_time, last_reset);
			APRS_backlog_store(bck_buffer, 37);
		}
		
		/* APRS Packet */
		uint8_t n;
		uint8_t aprs_buffer[150];
		
		n = APRS_packet(aprs_buffer, (uint8_t *)"OK7DMT", 2, lat, lon, (uint16_t)hMSL, MCU_temp, therm1_raw, therm2_raw, MS1_temp, MS2_temp,
						(uint32_t)MS1_pres, (uint32_t)MS2_pres, batt_V_raw, ambient_light, numSV, active_time, last_reset, &backlog_index, noGPS);
		APRS_prepare_bitstream(aprs_buffer, n);
		
		/* WatchDog Reset */
		WatchDog_reset();
		
		/* GeoFenced Frequency */
		uint32_t tx_frequency = GEOFENCE_frequency(lat, lon);		// decide on frequency based on GPS position
		
		/* APRS Transmission */
		if(tx_frequency > 144000000 && tx_frequency < 146000000)	// no transmission if tx_frequency equals 0 
		{
			/* FDPLL96M */
			NVM_wait_states(3);										// NVM Read Wait States: 0-15, default 0, 3 for 48MHz PL2 operation
			PM_set_performance_level(2, 0);
			OSC_enable_FDPLL96M(0, 0, 1545, 14);					// 50,688,000Hz FDPLL96M
			GCLK_x_enable(0, 8, 2, 0, 0);							// 25,344,000Hz MCLK - FDPLL96M / 2
			SysTick_CLK = 25344000;
			
			/* SI5351B & DAC */
			PORT_switch_enable(3);									// POWER to 3.3V on
			PORT_switch_enable(4);									// POWER to TRANSLATOR on
			SERCOM_I2C_enable(25344000, 90000);
			
			SI5351B_init();
			SI5351B_frequency(tx_frequency, 38);
			GCLK_x_enable(2, 8, 12, 0, 0);							// 4,224,000Hz GCLK[2]
			DAC_enable(1, 1);										// VDDANA, 1.2MHz-6MHz
			
			SI5351B_enable_output();
			TC0_enable(0x00, 660, 1);								// 25,344,000Hz, 660/65535 -> 38,400Hz
			TC4_enable(0x00, 360, 0);								// 25,344,000Hz, 360/65535 -> 70,400Hz
			TC0_transmission();
			TC4_disable();
			TC0_disable();
			SI5351B_disable_output();
			DAC_disable();
			SI5351B_deinit();
			
			SERCOM_I2C_disable();
			PORT_switch_disable(4);									// POWER to TRANSLATOR off
			PORT_switch_disable(3);									// POWER to 3.3V off
			
			/* XOSC32K */
			GCLK_x_enable(0, 5, 1, 0, 0);							// 32.768kHz MCLK - XOSC32K
			SysTick_CLK = 32768;
			OSC_disable_FDPLL96M();
			PM_set_performance_level(0, 0);
			NVM_wait_states(0);										// NVM Read Wait States: 0-15, default 0, 3 for 48MHz PL2 operation
		}
		else
		{
			/* XOSC32K */
			GCLK_x_enable(0, 5, 1, 0, 0);							// 32.768kHz MCLK - XOSC32K
			SysTick_CLK = 32768;
		}
		
		/* WatchDog Reset */
		WatchDog_reset();
		
		/* Sleep */
		for(uint8_t i = 0; i < 12; i++)								// 120s = 12 * 10s
		{
			RTC_mode0_update_compare(320);							// 10s sleep
		
			PM_set_sleepmode(4, 0, 0, 0, 0, 0);						// Standby, domains not linked, automatic mode, no sleepwalking, handled by HW
			PM_sleep();												// enter Standby
			
			/* WatchDog Reset */
			WatchDog_reset();										// WatchDog period 16s
		}
		
		/* Wake-Up */
		GCLK_x_enable(0, 6, 0, 0, 0);								// 4MHz MCLK - OSC16M
		SysTick_CLK = 4000000;
		
		/* Force Reset Check */
		if(reinit >= 5) RSTC_system_reset_request();				// reset MCU if too many positional fix failures in row
		
		RTC_mode0_set_count(0);										// reset RTC to count from 0 again
	}
}

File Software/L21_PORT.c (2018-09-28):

/*
	The IO Pin Controller (PORT) controls the I/O pins of the device.
	
	After reset, all standard function device I/O pads are connected to the PORT with outputs
	tri-stated and input buffers disabled, even if there is no clock running.
	
	PIN CONFIGURATIONS
		DIR		INEN	PULLEN	OUT		Configuration
		0		0		0		X		Reset or analog I/O: all digital disabled
		0		0		1		0		Pull-down; input disabled
		0		0		1		1		Pull-up; input disabled
		0		1		0		X		Input
		0		1		1		0		Input with pull-down
		0		1		1		1		Input with pull-up
		1		0		X		X		Output; input disabled
		1		1		X		X		Output; input enabled
*/


#include "sam.h"
#include "L21_PORT.h"


/*	
	SWTCH
	1		Load Switch - GPS			PA22		(external pull-down)
	2		Load Switch - Sensors		PA16		(external pull-down)
	3		Boost Converter - 3.3V		PA04		(external pull-down)
	4		Voltage Translator			PA06		(serves as 1.8V power supply)
*/
void PORT_switch_enable(uint8_t swtch)
{
	switch(swtch)
	{
		case 1:
			PORT->Group[0].DIRSET.reg = PORT_PA22;				// I/O pin in the PORT group is configured as an OUTPUT.
			PORT->Group[0].OUTSET.reg = PORT_PA22;				// Pin output is driven HIGH, or input is connected to an internal PULL-UP.
			break;
			
		case 2:
			PORT->Group[0].DIRSET.reg = PORT_PA16;				// I/O pin in the PORT group is configured as an OUTPUT.
			PORT->Group[0].OUTSET.reg = PORT_PA16;				// Pin output is driven HIGH, or input is connected to an internal PULL-UP.
			break;
			
		case 3:
			PORT->Group[0].DIRSET.reg = PORT_PA04;				// I/O pin in the PORT group is configured as an OUTPUT.
			PORT->Group[0].OUTSET.reg = PORT_PA04;				// Pin output is driven HIGH, or input is connected to an internal PULL-UP.
			break;
			
		case 4:
			PORT->Group[0].PINCFG[6].reg = (0x1 << 6);			// DRVSTR - Pin drive strength is set to stronger drive strength.
			PORT->Group[0].DIRSET.reg = PORT_PA06;				// I/O pin in the PORT group is configured as an OUTPUT.
			PORT->Group[0].OUTSET.reg = PORT_PA06;				// Pin output is driven HIGH, or input is connected to an internal PULL-UP.
			break;
			
		default:
			break;
	}
}


/*
	SWTCH
	1		Load Switch - GPS			PA22		(external pull-down)
	2		Load Switch - Sensors		PA16		(external pull-down)
	3		Boost Converter - 3.3V		PA04		(external pull-down)
	4		Voltage Translator			PA06		(serves as 1.8V power supply)
*/
void PORT_switch_disable(uint8_t swtch)
{
	switch(swtch)
	{
		case 1:
			PORT->Group[0].OUTCLR.reg = PORT_PA22;				// Pin output is driven LOW, or input is connected to an internal PULL-DOWN.
			PORT->Group[0].DIRCLR.reg = PORT_PA22;				// I/O pin in the PORT group is configured as an INPUT.
			break;
			
		case 2:
			PORT->Group[0].OUTCLR.reg = PORT_PA16;				// Pin output is driven LOW, or input is connected to an internal PULL-DOWN.
			PORT->Group[0].DIRCLR.reg = PORT_PA16;				// I/O pin in the PORT group is configured as an INPUT.
			break;
			
		case 3:
			PORT->Group[0].OUTCLR.reg = PORT_PA04;				// Pin output is driven LOW, or input is connected to an internal PULL-DOWN.
			PORT->Group[0].DIRCLR.reg = PORT_PA04;				// I/O pin in the PORT group is configured as an INPUT.
			break;
			
		case 4:
			PORT->Group[0].OUTCLR.reg = PORT_PA06;				// Pin output is driven LOW, or input is connected to an internal PULL-DOWN.
			PORT->Group[0].DIRCLR.reg = PORT_PA06;				// I/O pin in the PORT group is configured as an INPUT.
			break;
			
		default:
			break;
	}
}

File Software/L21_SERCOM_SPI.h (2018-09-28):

/*
	The serial peripheral interface (SPI) is one of the available modes in the Serial Communication Interface (SERCOM).
	
	TT7B TRACKER
		PA14	CS1		GPIO			-			-
		PA15	CS2		GPIO			-			-
		PA17	MISO	SERCOM 1/3		Pad[1]		Peripheral function C/D
		PA18	MOSI	SERCOM 1/3		Pad[2]		Peripheral function C/D
		PA19	SCLK	SERCOM 1/3		Pad[3]		Peripheral function C/D
*/


#ifndef L21_SERCOM_SPI_H
#define L21_SERCOM_SPI_H


#include "stdint.h"


// Functions
void SERCOM_SPI_enable(void);
void SERCOM_SPI_disable(void);
void SERCOM_SPI_reset(void);
uint8_t SERCOM_SPI_transmission(uint8_t data);


#endif // L21_SERCOM_SPI_H_
